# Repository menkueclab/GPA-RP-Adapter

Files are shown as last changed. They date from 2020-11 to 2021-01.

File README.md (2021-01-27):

# GPA-RP-Adapter
This is a shield for the red pitaya (rp-122 or rp-125) to connect it easily to the GPA-FHDO.

# Parts
- pin header
- RJ45 connector
- schmitt trigger (optional)
- SMA connector  (optional)
- capacitor  (optional)
- fan (optional)

for details see KiCad schematic.

# Contributing
Benjamin Menkuec

# Disclaimer
Not intended for medical use!

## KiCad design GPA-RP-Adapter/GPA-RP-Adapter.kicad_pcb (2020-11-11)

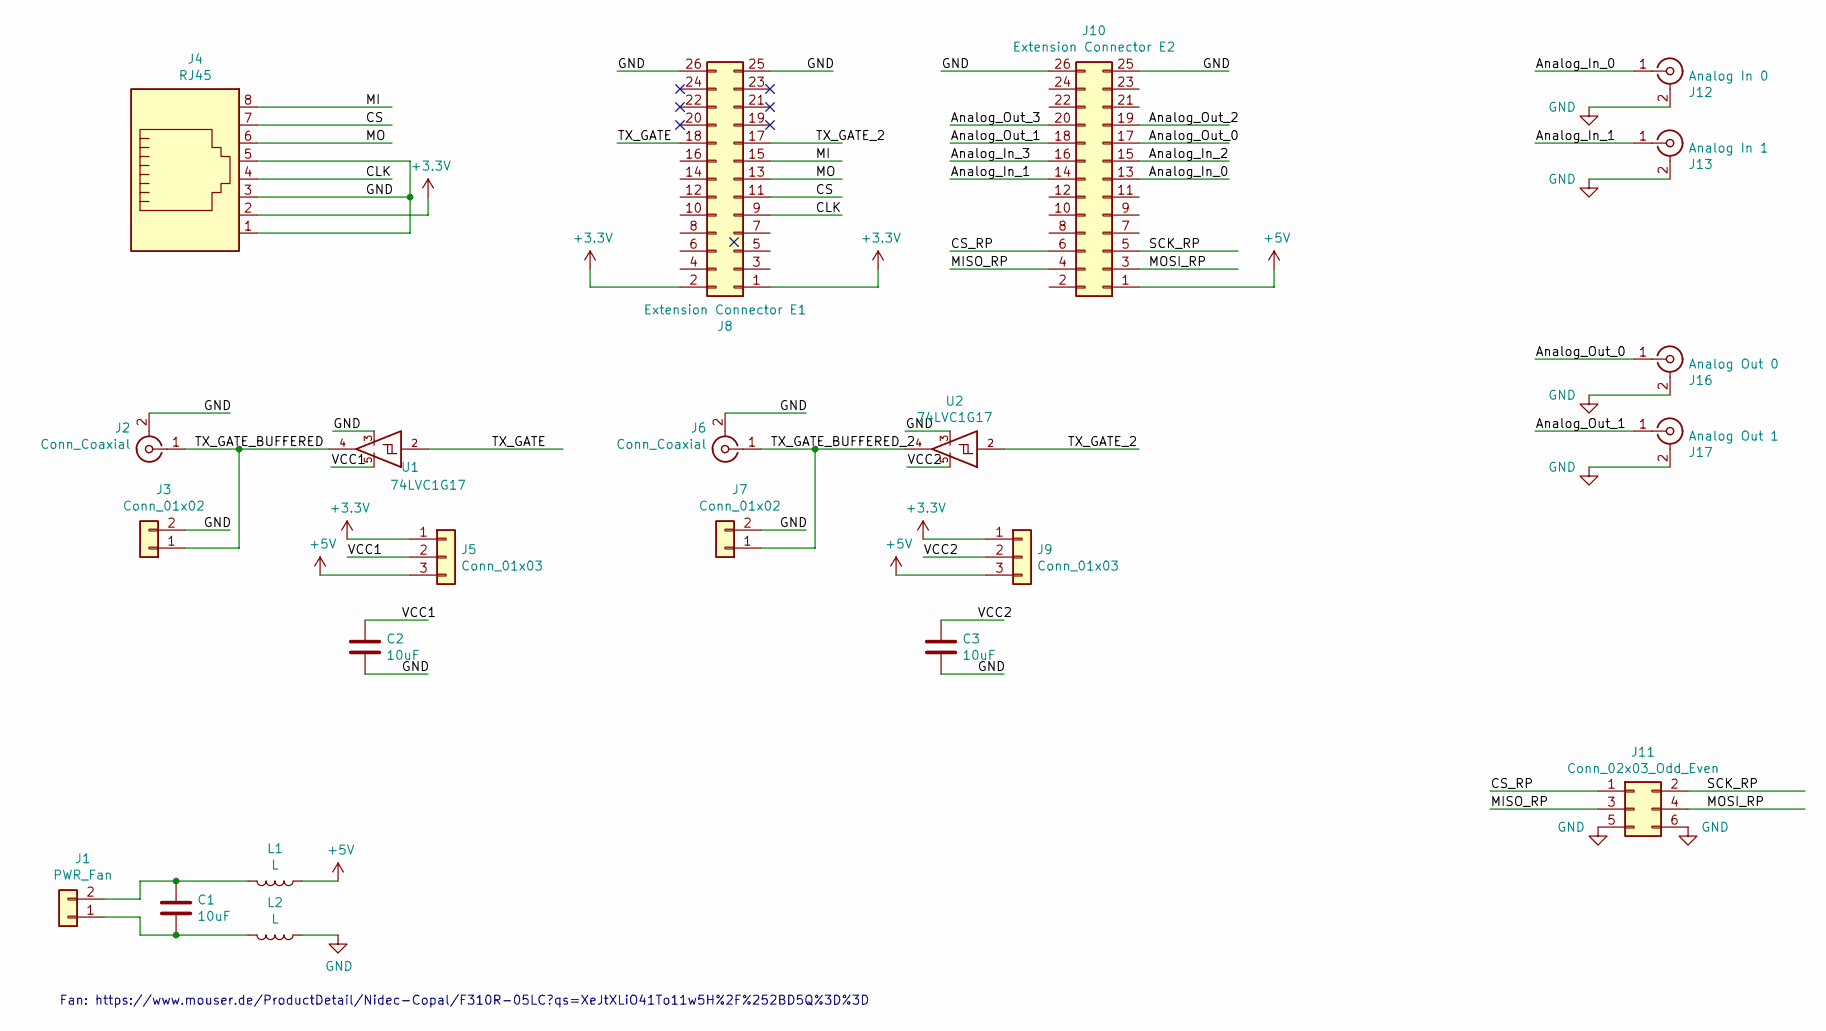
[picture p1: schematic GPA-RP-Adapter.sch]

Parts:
C1, C2, C3: 10uF; C_0805_2012Metric_Pad1.15x1.40mm_HandSolder
J1: PWR_Fan; PinHeader_1x02_P2.54mm_Vertical
J2, J6: Conn_Coaxial; SMA_Amphenol_132134_Vertical
J3, J7: Conn_01x02; PinHeader_1x02_P2.54mm_Vertical
J4: RJ45; RJ45_Amphenol_54602-x08_Horizontal
J5, J9: Conn_01x03; PinHeader_1x03_P2.54mm_Vertical
J8: Extension Connector E1; PinHeader_2x13_P2.54mm_Vertical
J10: Extension Connector E2; PinHeader_2x13_P2.54mm_Vertical
J11: Conn_02x03_Odd_Even; PinHeader_2x03_P2.54mm_Vertical
J12: Analog In 0; SMA_Amphenol_132134_Vertical
J13: Analog In 1; SMA_Amphenol_132134_Vertical
J16: Analog Out 0; SMA_Amphenol_132134_Vertical
J17: Analog Out 1; SMA_Amphenol_132134_Vertical
L1, L2: L; L_0805_2012Metric_Pad1.15x1.40mm_HandSolder
U1, U2: 74LVC1G17; SOT-23-5_HandSoldering

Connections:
+3V3: J4.2, J5.1, J8.1, J8.2, J9.1; also elsewhere on the board
+5V: J5.3, J9.3, J10.1, L1.1; also elsewhere on the board
/Analog_In_0: J10.13, J12.1 (In); also elsewhere on the board
/Analog_In_1: J10.14, J13.1 (In); also elsewhere on the board
/Analog_Out_0: J10.17, J16.1 (In); also elsewhere on the board
/Analog_Out_1: J10.18, J17.1 (In); also elsewhere on the board
/CLK: J4.4, J8.9; also elsewhere on the board
/CS: J4.7, J8.11; also elsewhere on the board
/CS_RP: J10.6, J11.1; also elsewhere on the board
/MI: J4.8, J8.15; also elsewhere on the board
/MISO_RP: J10.4, J11.3; also elsewhere on the board
/MO: J4.6, J8.13; also elsewhere on the board
/MOSI_RP: J10.3, J11.4; also elsewhere on the board
/SCK_RP: J10.5, J11.2; also elsewhere on the board
/TX_GATE: J8.18, U1.2; also elsewhere on the board
/TX_GATE_2: J8.17, U2.2; also elsewhere on the board
/TX_GATE_BUFFERED: J2.1 (In), J3.1, U1.4
/TX_GATE_BUFFERED_2: J6.1 (In), J7.1, U2.4
/VCC1: C2.1, J5.2, U1.5
/VCC2: C3.1, J9.2, U2.5
GND: C2.2, C3.2, J2.2 (Ext), J3.2, J4.1, J4.3, J4.5, J6.2 (Ext), J7.2, J8.25, J8.26, J10.25, J10.26, J11.5, J11.6, J12.2 (Ext), J13.2 (Ext), J16.2 (Ext), J17.2 (Ext), L2.1, U1.3, U2.3; also elsewhere on the board
unnamed: C1.1, J1.2, L1.2
unnamed: C1.2, J1.1, L2.2

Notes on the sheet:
Fan: https://www.mouser.de/ProductDetail/Nidec-Copal/F310R-05LC?qs=XeJtXLiO41To11w5H%2F%252BD5Q%3D%3D

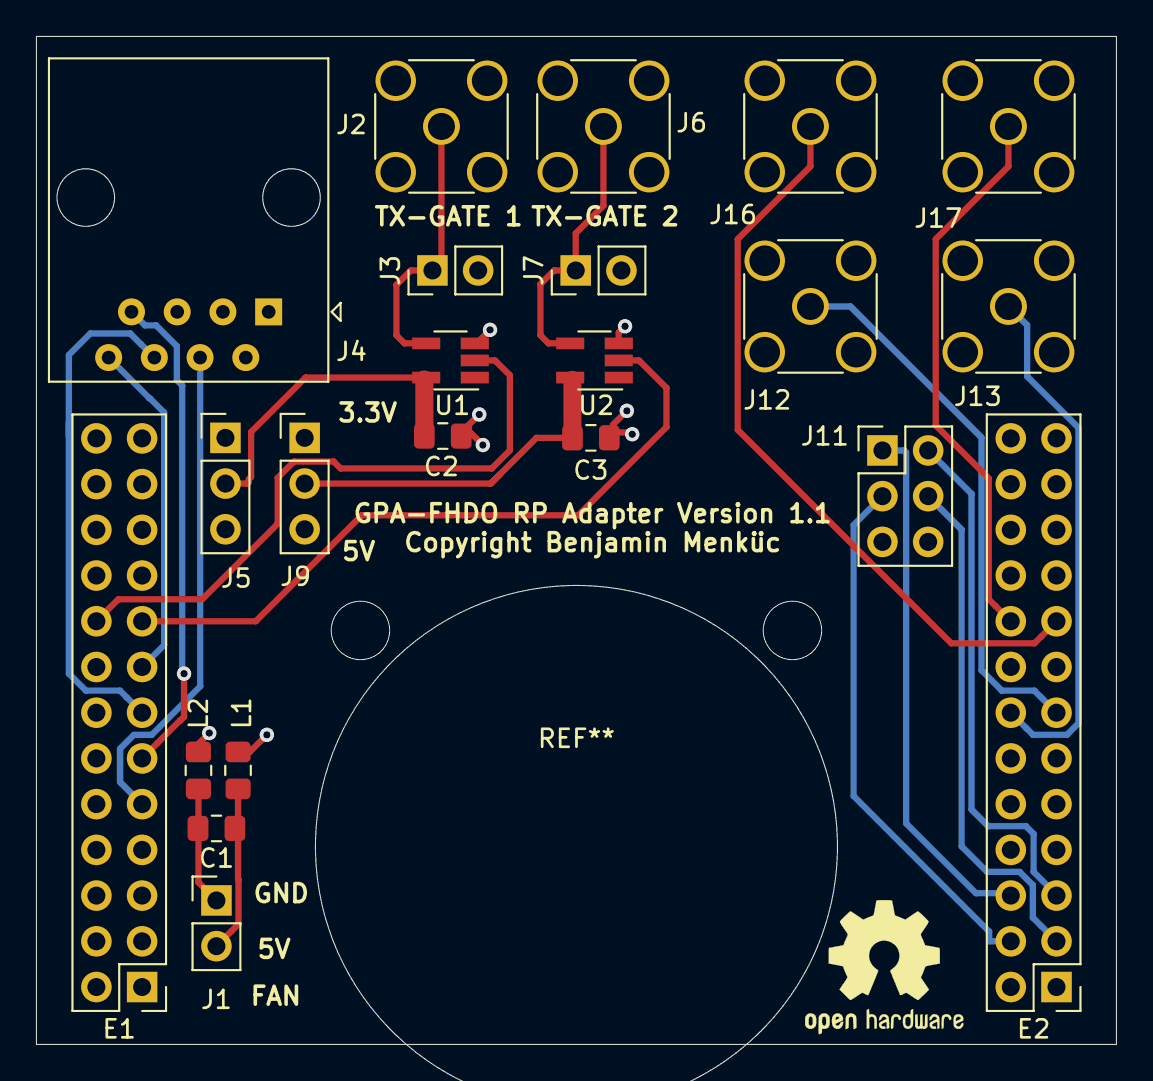
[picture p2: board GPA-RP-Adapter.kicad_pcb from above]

Board: 4 copper layers, 60.0 x 56.0 mm, 22 parts (0 on the bottom side), 23 nets.

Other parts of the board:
E1: Extension Connector E1; PinHeader_2x13_P2.54mm_Vertical
E2: Extension Connector E2; PinHeader_2x13_P2.54mm_Vertical

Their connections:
+3V3: E1.1, E1.2; also elsewhere on the board
+5V: E2.1; also elsewhere on the board
/Analog_In_0: E2.13; also elsewhere on the board
/Analog_In_1: E2.14; also elsewhere on the board
/Analog_Out_0: E2.17; also elsewhere on the board
/Analog_Out_1: E2.18; also elsewhere on the board
/CLK: E1.9; also elsewhere on the board
/CS: E1.11; also elsewhere on the board
/CS_RP: E2.6; also elsewhere on the board
/MI: E1.15; also elsewhere on the board
/MISO_RP: E2.4; also elsewhere on the board
/MO: E1.13; also elsewhere on the board
/MOSI_RP: E2.3; also elsewhere on the board
/SCK_RP: E2.5; also elsewhere on the board
/TX_GATE: E1.18; also elsewhere on the board
/TX_GATE_2: E1.17; also elsewhere on the board
GND: E1.25, E1.26, E2.25, E2.26; also elsewhere on the board

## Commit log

2020-10-12 completed schematic
    [GPA-RP-Adapter.kicad_pcb, GPA-RP-Adapter.sch]
2020-10-12 added 2nd tx_gate
    [GPA-RP-Adapter.sch]
2020-10-12 added analog IOs, SPI and fan
    [GPA-RP-Adapter.sch]
2020-10-12 added PWR connector for fan
    [GPA-RP-Adapter.sch]
2020-10-15 finished layout
    [GPA-RP-Adapter.kicad_pcb, GPA-RP-Adapter.sch]
2020-11-11 fixed some errors in layout - rotated rj45 connector - connected the 5V layer properly
    [GPA-RP-Adapter.kicad_pcb]

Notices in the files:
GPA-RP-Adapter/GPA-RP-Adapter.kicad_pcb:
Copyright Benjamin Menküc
